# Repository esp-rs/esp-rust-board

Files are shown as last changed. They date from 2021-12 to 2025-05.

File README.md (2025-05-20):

# Rust ESP Board

Welcome to the Rust ESP Development board project. This repository contains everything you will need to build the board yourself.

## Where to buy

* [ESP32-C3-DevKit-RUST-1](https://www.espressif.com/en/products/devkits)
* [AliExpress Espressif Official Store](https://www.aliexpress.com/item/1005004418342288.html)
* [Mouser Electronics](https://www2.mouser.com/ProductDetail/Espressif-Systems/ESP32-C3-DevKit-RUST-1?qs=4ASt3YYao0WvXOj9TGjU2A%3D%3D)
(Note that at least when ordering from the UK and seemingly [EU and Europe](https://www.mouser.co.uk/saleterms/), if you choose to
order through Mouser there is long process instigated by email post-checkout to fill out and then electronically sign or fax export declaration forms
which can add significant delay)

## Ferrous Systems Training

* [Training Book: Explore the power of Rust on the new Espressif board](https://github.com/esp-rs/std-training)
  * [Training Material](https://esp-rs.github.io/std-training/)

## Project Specification

This board is based on the ESP32-C3, and includes sensors, LEDs, buttons, a battery charger, and USB type-C connector.

### SoC Features

* IEEE 802.11 b/g/n-compliant
* Bluetooth 5, Bluetooth mesh
* 32-bit RISC-V single-core processor, up to 160MHz
* 384 KB ROM
* 400 KB SRAM (16 KB for cache)
* 8 KB SRAM in RTC
* 22 × programmable GPIOs
* 3 × SPI
* 2 × UART
* 1 × I2C
* 1 × I2S
* 2 × 54-bit general-purpose timers
* 3 × watchdog timers
* 1 × 52-bit system timer
* Remote Control Peripheral (RMT)
* LED PWM controller (LEDC)
* Full-speed USB Serial/JTAG controller
* General DMA controller (GDMA)
* 1 × TWAI®
* 2 × 12-bit SAR ADCs, up to 6 channels
* 1 × temperature sensor

For the complete description, see the [ESP32-C3 Datasheet](https://www.espressif.com/sites/default/files/documentation/esp32-c3_datasheet_en.pdf).

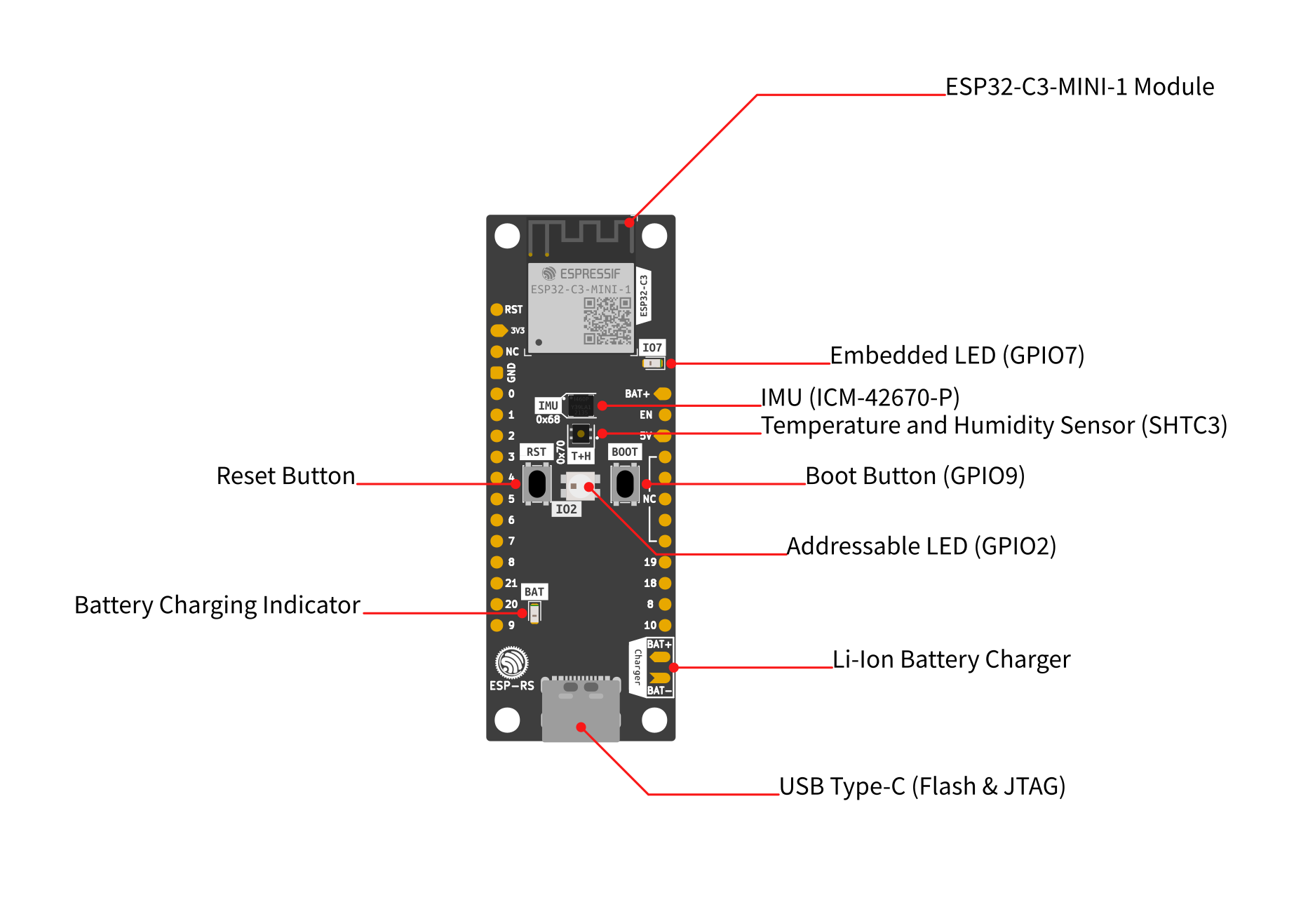
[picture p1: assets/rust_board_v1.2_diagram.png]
Diagram


### I2C Peripherals

This board includes the following peripherals over the I2C bus:

| Peripheral | Part number | Reference | Crate | Address |
| --- | --- | --- | --- | --- |
| IMU | ICM-42670-P | [Datasheet](https://invensense.tdk.com/download-pdf/icm-42670-p-datasheet/) | [Link](https://crates.io/crates/icm42670) | 0x68 |
| Temperature and Humidity | SHTC3 | [Datasheet](https://www.mouser.com/datasheet/2/682/Sensirion_04202018_HT_DS_SHTC3_Preliminiary_D2-1323493.pdf) | [Link](https://crates.io/crates/shtcx) | 0x70 |

#### I2C Bus Connection

| Signal | GPIO |
| --- | --- |
| SDA | GPIO10 |
| SCL | GPIO8  |

### I/Os

The following devices are connected through GPIO:

| I/O Devices | GPIO  |
| --- | ----- |
| WS2812 LED  | GPIO2 |
| LED | GPIO7 |
| Button/Boot | GPIO9 |

### Power

* USB type-C (*no PD compatibility*).
* Li-Ion battery charger - MCP73831T-2ACI/OT, it charges up to 4.2V.
  * Recommendation: MCP73831T-2ACI/OT does not provide battery protection for over-current or over-discharge. For the battery (Li-Ion or Li-Po), it's recommended the ones with embedded protection
  * Limitation: reading the battery voltage is not supported.

### Pin Layout

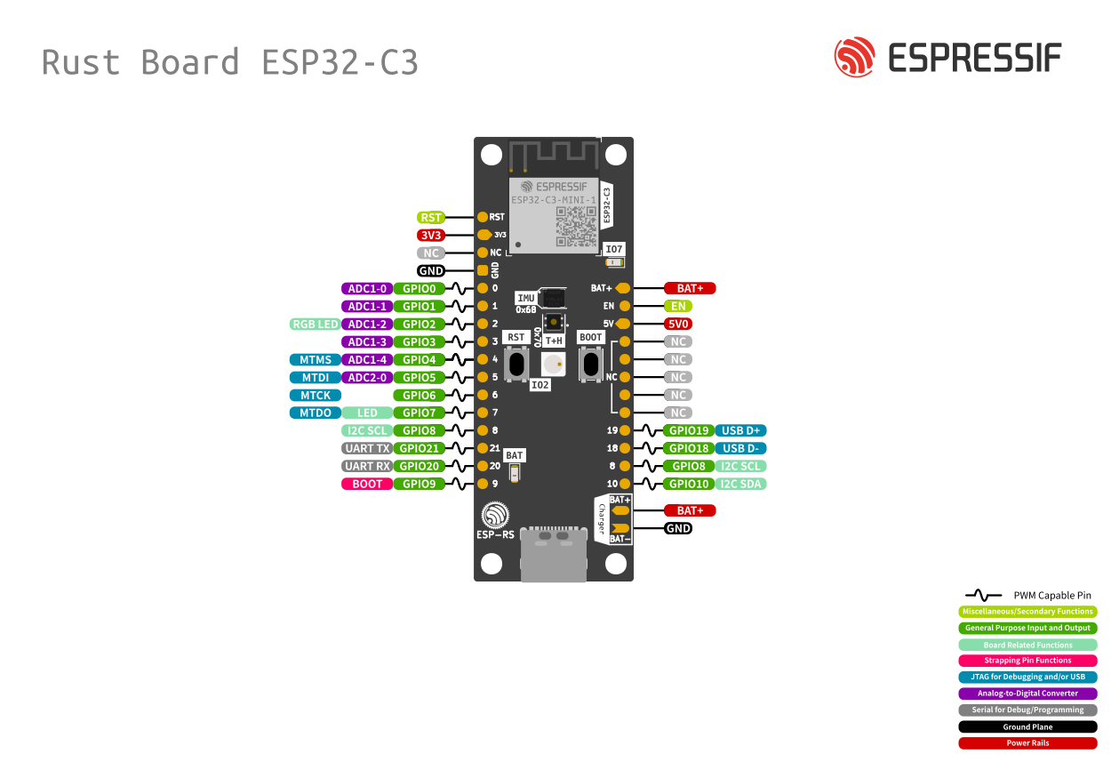
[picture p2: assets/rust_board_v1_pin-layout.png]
Pin Layout


#### Left Side

| Pin Number | Description  | SoC |
| --- | --- | --- |
| 1 | Reset | EN/CHIP_PU |
| 2 | 3V3 | |
| 3 | N/C | |
| 4 | GND | |
| 5 | IO0/ADC1-0 | GPIO0 |
| 6 | IO1/ADC1-1 | GPIO1 |
| 7 | IO2/ADC1-2 | GPIO2 |
| 8 | IO3/ADC1-3 | GPIO3 |
| 9 | IO4/ADC2-0 | GPIO4 |
| 10 | IO5/ADC2-1 | GPIO5 |
| 11 | IO6/MTCK | GPIO6 |
| 12 | IO7/MTDO/LED | GPIO7 |
| 13 | IO9/LOG | GPIO8 |
| 14 | IO21/U0RXD | GPIO21 |
| 15 | IO20/U0TXD | GPIO20 |
| 16 | IO9/BOOT | GPIO9 |

#### Right Side

| Pin Number | Description | SoC |
| --- | --- | --- |
| 1 | VBAT | |
| 2 | EN [1] | |
| 3 | VBUS [2] | |
| 4 | NC | |
| 5 | NC | |
| 6 | NC | |
| 7 | NC | |
| 8 | NC | |
| 9 | IO18/USB_D- | GPIO18 |
| 10 | IO19/USB_D+ | GPIO19 |
| 11 | IO8/SCL | GPIO8  |
| 12 | IO10/SDA | GPIO10 |

  * [1] Connected to LDO enable pin*
  * [2] Connected to USB 5V*

## Project KiCad Libraries

* [ESP32C3](https://github.com/espressif/kicad-libraries)

## Board Design

Top

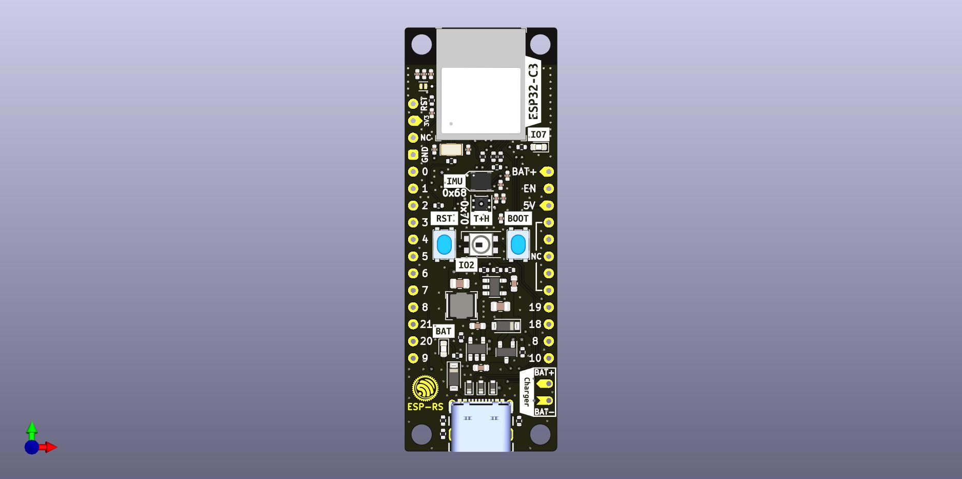
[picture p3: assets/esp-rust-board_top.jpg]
TOP


Bottom

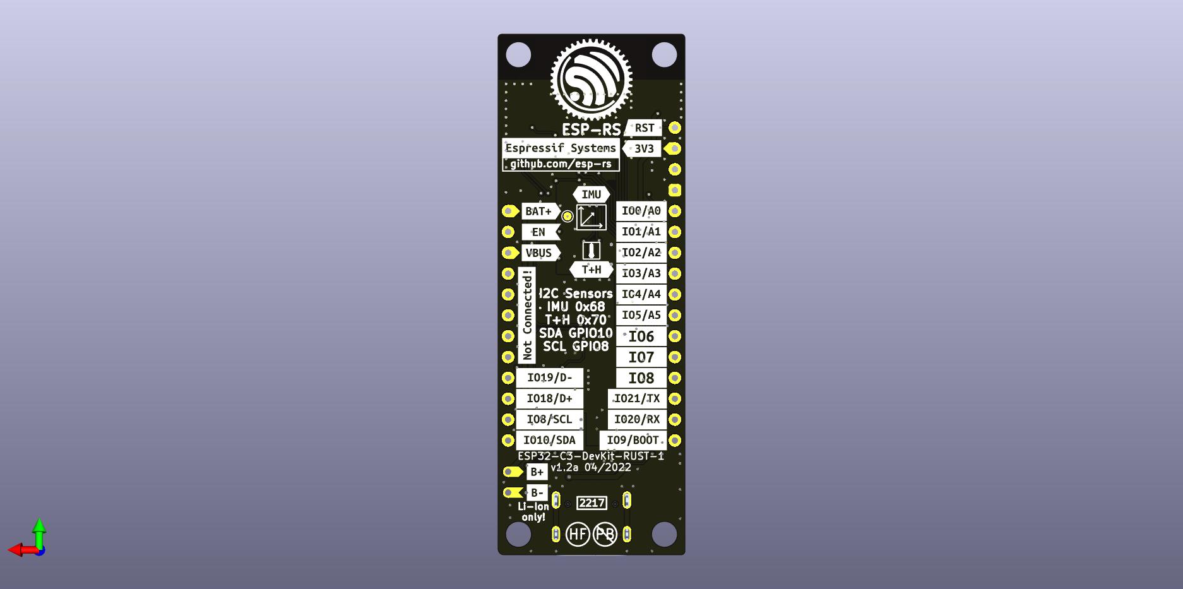
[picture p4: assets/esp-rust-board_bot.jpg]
BOT


## Bill of Material

[Interactive BOM](https://esp-rs.github.io/esp-rust-board/)

## Case

[Case 3D Printing Model](https://www.printables.com/model/288200-minimalistic-case-for-esp32-c3-devkit-rust-1)

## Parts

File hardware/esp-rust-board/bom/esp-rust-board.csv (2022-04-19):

Source: | /home/pedro/Documents/espressif/github/esp-rust-board/hardware/esp-rust-board/esp-rust-board.kicad_sch
Date: | ter 19 abr 2022 15:32:31
Tool: | Eeschema 6.0.1-79c1e3a40b~116~ubuntu21.04.1
Generator: | /usr/share/kicad/plugins/bom_csv_grouped_by_value_with_fp.py
Component Count: | 46
Ref | Qnty | Value | Cmp name | Footprint | Description | Vendor
C1, C2, C11, | 3 | 10nF 10V | C_Small | Capacitor_SMD:C_0402_1005Metric | Unpolarized capacitor, small symbol
C3, C4, C9, | 3 | 100nF 10V | C_Small | Capacitor_SMD:C_0402_1005Metric | Unpolarized capacitor, small symbol
C5, C7, | 2 | 10uF 16V | C_Small | Capacitor_SMD:C_0805_2012Metric | Unpolarized capacitor, small symbol
C6, | 1 | 22pF 50V | C_Small | Capacitor_SMD:C_0603_1608Metric | Unpolarized capacitor, small symbol
C8, C10, | 2 | 1uF 16V | C_Small | Capacitor_SMD:C_0402_1005Metric | Unpolarized capacitor, small symbol
C15, C16, | 2 | 4.7uF 16V | C_Small | Capacitor_SMD:C_0603_1608Metric | Unpolarized capacitor, small symbol
D1, | 1 | LESD8D3.3CAT5G | D_TVS | Rust_Board:SOD-882 | Bidirectional transient-voltage-suppression diode
D2, D3, | 2 | LED | LED | LED_SMD:LED_0603_1608Metric | Light emitting diode
D4, D6, | 2 | B5819W | D_Schottky | Diode_SMD:D_SOD-123 | Schottky diode
D5, D7, D8, | 3 | LESD5D5.0CT1G | D_TVS | Diode_SMD:D_SOD-523 | Bidirectional transient-voltage-suppression diode
J1, | 1 | USB4105-GF-A | USB4105-GF-A | Rust_Board:GCT_USB4105-GF-A
L1, | 1 | SPH4018H2R2MT (2.2uH 2.2A) | L_Small | Inductor_SMD:L_Bourns-SRN4018 | Inductor, small symbol
Q1, | 1 | DMG3415U | DMG2301L | Package_TO_SOT_SMD:SOT-23 | -3A Id, -20V Vds, P-Channel MOSFET, SOT-23
R1, | 1 | 10kR | R_Small_US | Resistor_SMD:R_0402_1005Metric | Resistor, small US symbol
R2, R15, | 2 | 100kR 1% | R_Small_US | Resistor_SMD:R_0402_1005Metric | Resistor, small US symbol
R3, | 1 | 22k1R 1% | R_Small_US | Resistor_SMD:R_0402_1005Metric | Resistor, small US symbol
R4, R6, | 2 | 5k1R 1% | R_Small_US | Resistor_SMD:R_0402_1005Metric | Resistor, small US symbol
R5, R7, | 2 | 0R 1% | R_Small_US | Resistor_SMD:R_0402_1005Metric | Resistor, small US symbol
R8, R9, R17, R18, R19, | 5 | 10kR 1% | R_Small_US | Resistor_SMD:R_0402_1005Metric | Resistor, small US symbol
R10, | 1 | 470R 1% | R_Small_US | Resistor_SMD:R_0402_1005Metric | Resistor, small US symbol
R14, | 1 | 1kR 1% | R_Small_US | Resistor_SMD:R_0402_1005Metric | Resistor, small US symbol
SW1, SW2, | 2 | SW_Push | SW_Push | Button_Switch_SMD:SW_SPST_PTS810 | Push button switch, generic, two pins
U1, | 1 | SHTC3 | SHTC3 | Rust_Board:SON100P200X200X80-5N
U2, | 1 | ICM-42670-P | ICM-42670-P | Rust_Board:IC_ICM-42670-P
U3, | 1 | ESP32-C3-MINI-1 | ESP32-C3-MINI-1 | Espressif:ESP32-C3-MINI-1
U5, | 1 | SY8088 | SY8088 | Package_TO_SOT_SMD:SOT-23-5
U6, | 1 | MCP73831-2-OT | MCP73831-2-OT | Package_TO_SOT_SMD:SOT-23-5 | Single cell, Li-Ion/Li-Po charge management controller, 4.20V, Tri-State Status Output, in SOT23-5 package

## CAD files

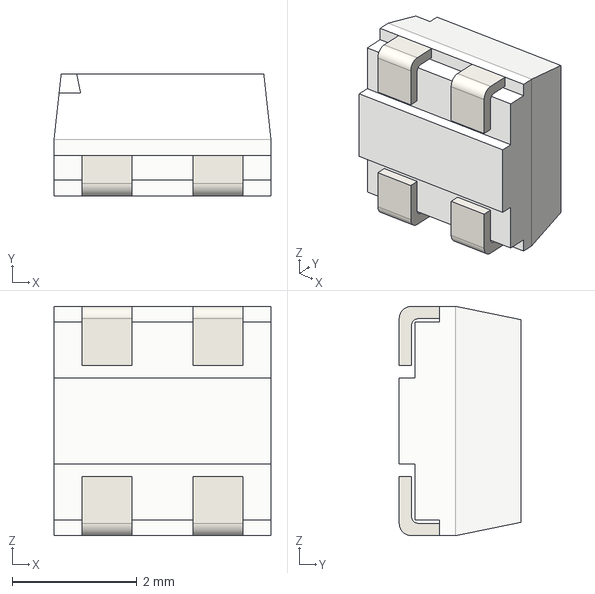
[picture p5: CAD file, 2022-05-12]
kicad_libs/3d/WS2812B-MINI.step
3.48 x 1.95 x 3.68 mm

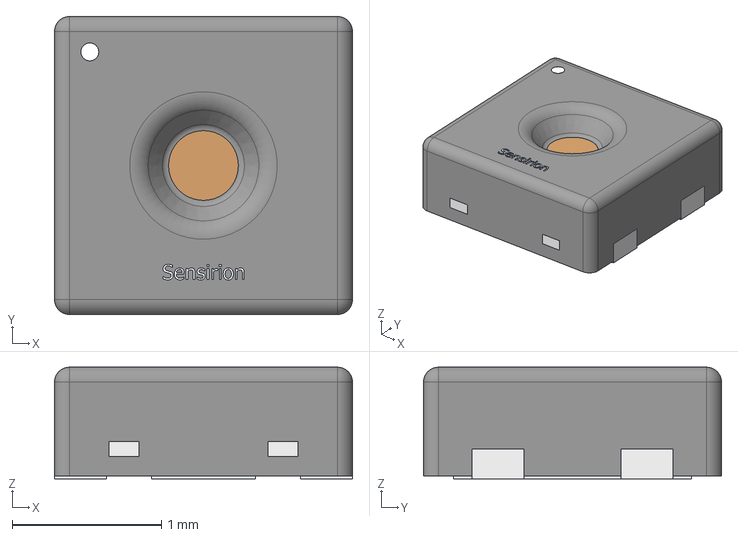
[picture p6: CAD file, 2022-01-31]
kicad_libs/3d/SHTC3.step
2.00 x 2.00 x 0.751 mm

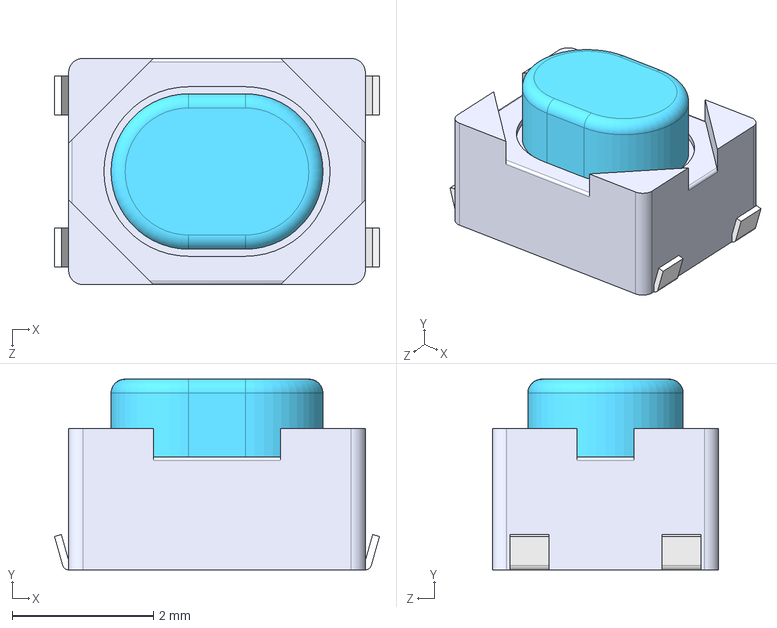
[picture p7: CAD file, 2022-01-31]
kicad_libs/3d/PTS810SJK250SMTRLFS.step
4.60 x 2.70 x 3.20 mm

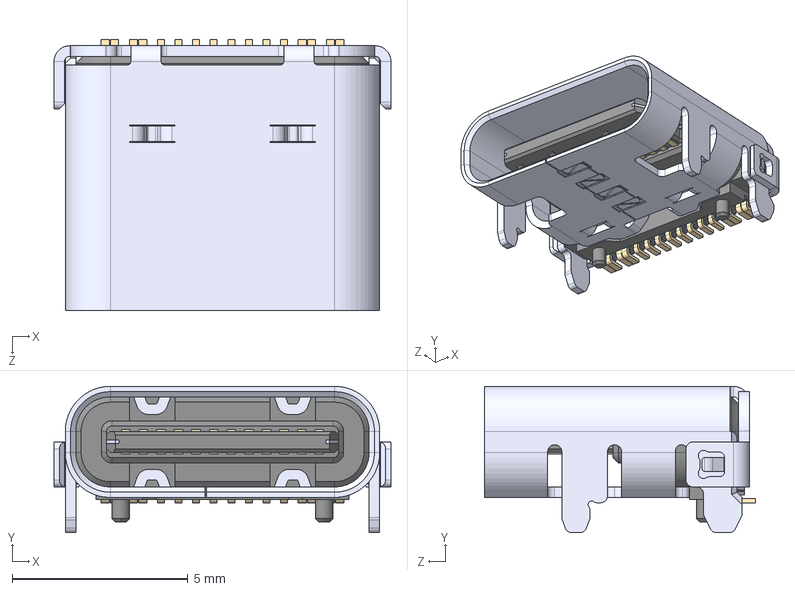
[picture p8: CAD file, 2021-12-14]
kicad_libs/3d/USB4105-GF-A.step
9.58 x 4.16 x 7.71 mm

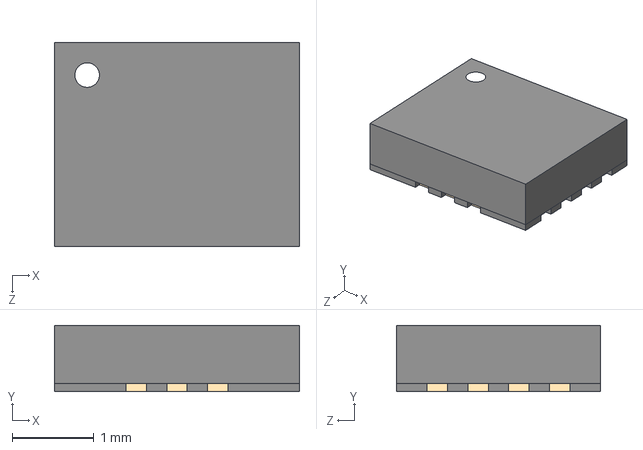
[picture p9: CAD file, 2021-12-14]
kicad_libs/3d/ICM-42670-P.step
3.00 x 0.81 x 2.50 mm

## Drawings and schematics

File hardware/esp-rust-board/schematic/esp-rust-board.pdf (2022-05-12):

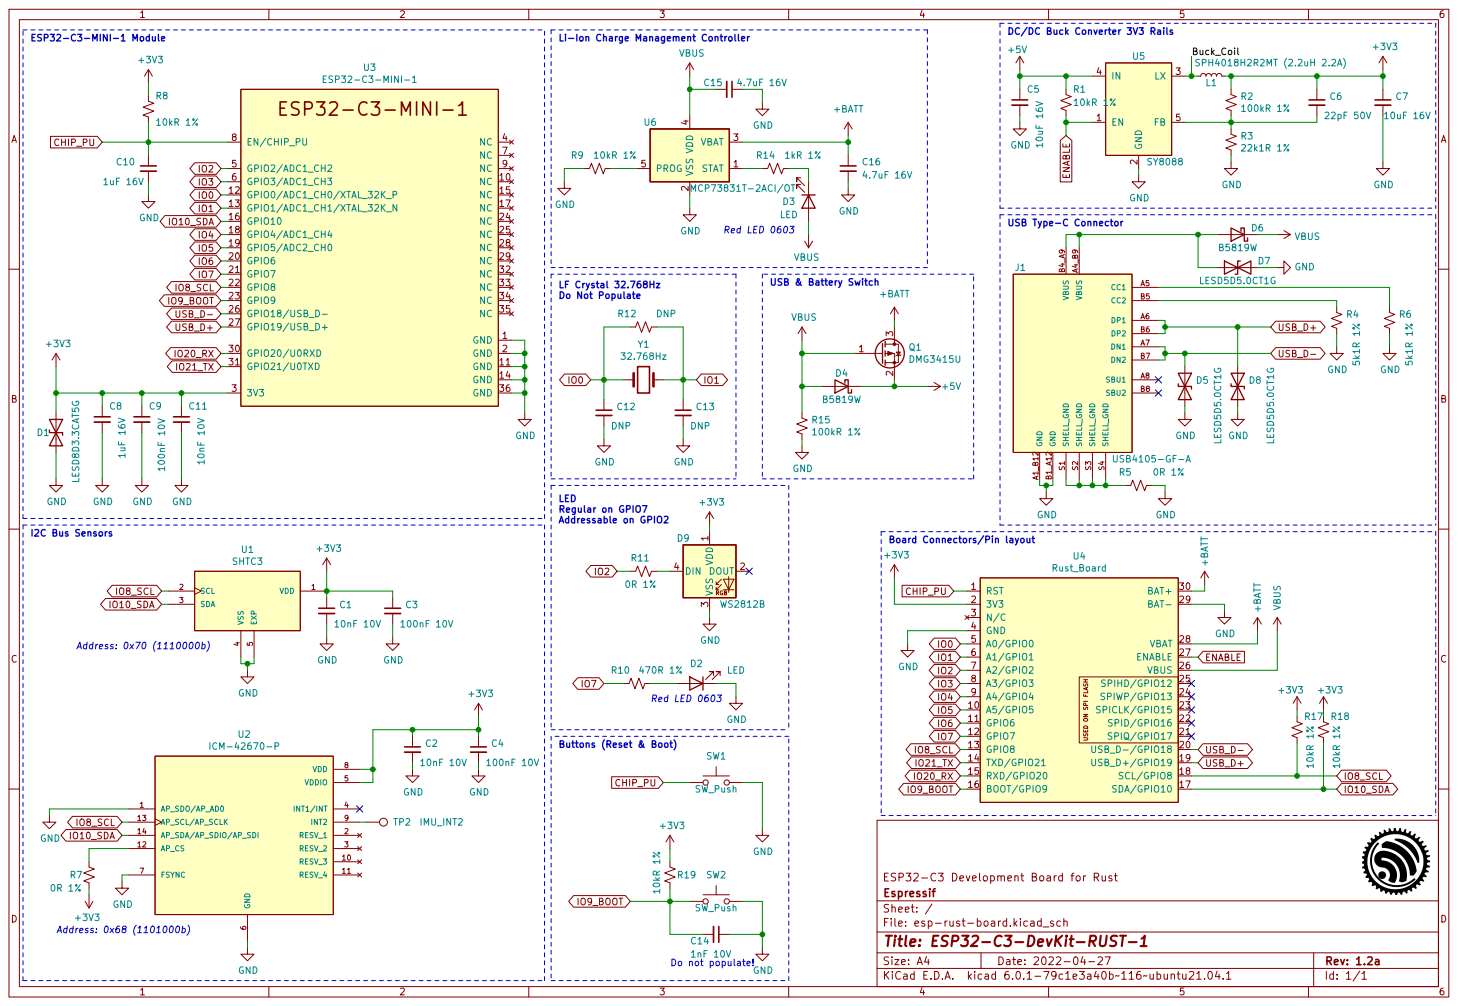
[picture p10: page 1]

Li-Ion Charge Management Controller

ESP32-C3 Development Board for Rust GND

Board Connectors/Pin layout

File: esp-rust-board.kicad_sch Sheet: / Espressif

Id: 1/1 Title: ESP32-C3-DevKit-RUST-1

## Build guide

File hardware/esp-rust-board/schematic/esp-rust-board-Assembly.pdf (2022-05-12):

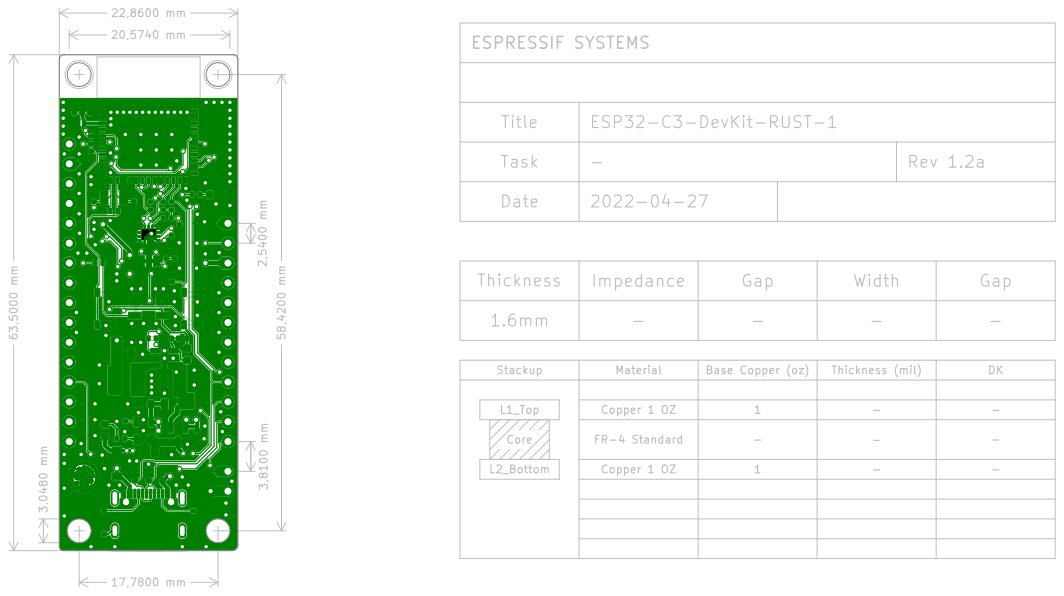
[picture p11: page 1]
D Date: 2022-04-27 KiCad E.D.A. kicad 6.0.1-79c1e3a40b~116~ubuntu21.04.1 Size: A4; Rev: 1.2a; - Stackup; Thickness (mil) L1_Top 1.6mm; Width; - Gap Date Thickness; Rev 1.2a ESPRESSIF SYSTEMS; Core; Gap; L2_Bottom; 1 Title; REF**; PCB-EDGE

ESP32-C3-DevKit-RUST-1 Task

2022-04-27
- Copper 1 OZ | | | DK

- Copper 1 OZ Material Impedance

- Base Copper (oz)

1 | - FR-4 Standard

Espressif Systems
Sheet: Assembly
File: esp-rust-board.kicad_pcb
Id: 1/1 Title: ESP32-C3-DevKit-RUST-1

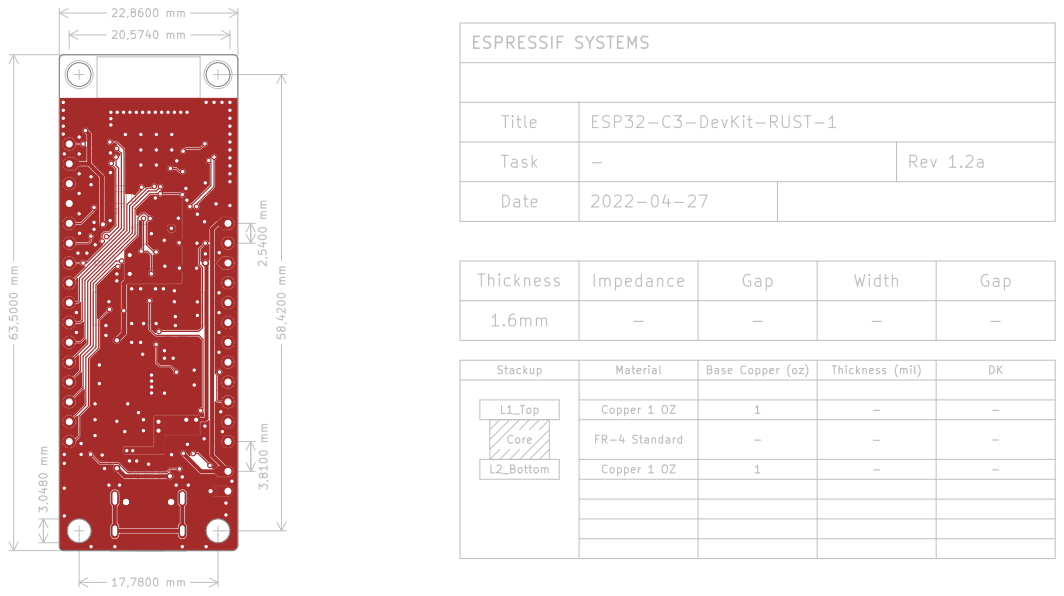
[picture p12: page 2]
D Date: 2022-04-27 KiCad E.D.A. kicad 6.0.1-79c1e3a40b~116~ubuntu21.04.1 Size: A4; Rev: 1.2a; - Stackup; Thickness (mil) L1_Top 1.6mm; Width; - Gap Date Thickness; Rev 1.2a ESPRESSIF SYSTEMS; Core; Gap; L2_Bottom; 1 Title; REF**; PCB-EDGE

ESP32-C3-DevKit-RUST-1 Task

- Copper 1 OZ Material Impedance

- Copper 1 OZ | | | DK

- Base Copper (oz)

1 | - FR-4 Standard

Espressif Systems
Sheet: Assembly
File: esp-rust-board.kicad_pcb
Id: 1/1 Title: ESP32-C3-DevKit-RUST-1

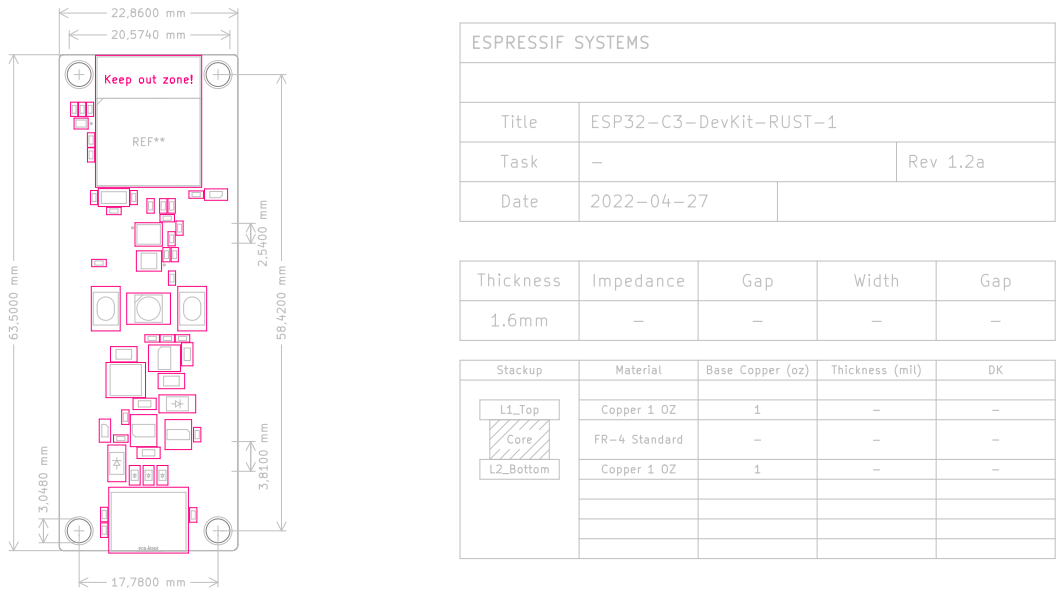
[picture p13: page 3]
D Date: 2022-04-27 KiCad E.D.A. kicad 6.0.1-79c1e3a40b~116~ubuntu21.04.1 Size: A4; Rev: 1.2a; - Stackup; Thickness (mil) L1_Top 1.6mm; Width; - Gap Date Thickness; Rev 1.2a ESPRESSIF SYSTEMS; Core; Gap; L2_Bottom; 1 Title; REF**

PCB-EDGE Keep out zone!

ESP32-C3-DevKit-RUST-1 Task

- Copper 1 OZ Material Impedance

- Copper 1 OZ | | | DK

- Base Copper (oz)

1 | - FR-4 Standard

Espressif Systems
Sheet: Assembly
File: esp-rust-board.kicad_pcb
Id: 1/1 Title: ESP32-C3-DevKit-RUST-1

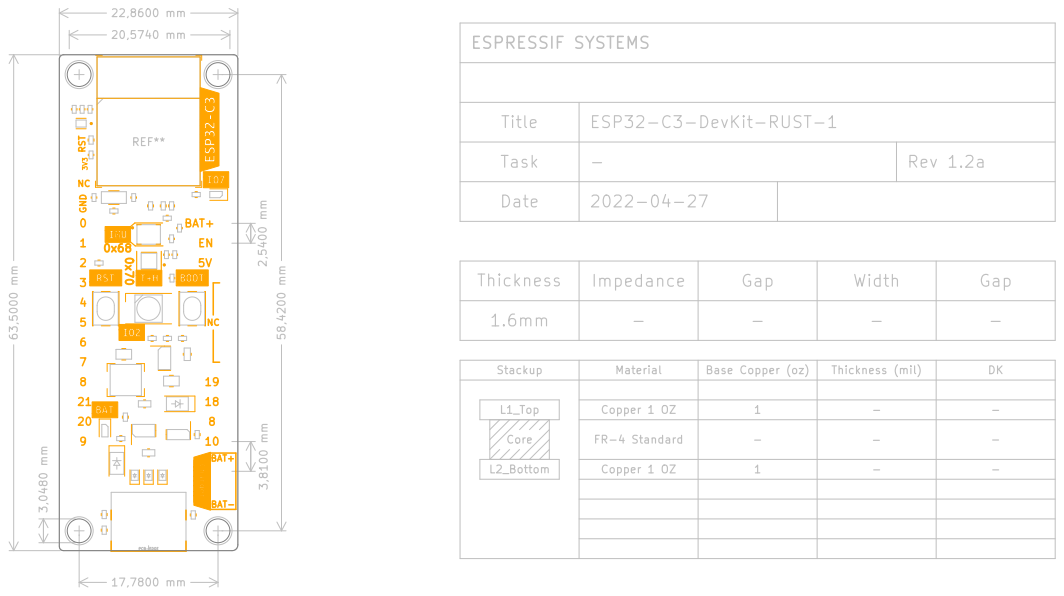
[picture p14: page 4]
D Date: 2022-04-27 KiCad E.D.A. kicad 6.0.1-79c1e3a40b~116~ubuntu21.04.1 Size: A4; Rev: 1.2a; - Stackup; Thickness (mil) L1_Top 1.6mm; Width; - Gap Date Thickness; Rev 1.2a ESPRESSIF SYSTEMS; Core; Gap; L2_Bottom; 1 Title; REF**; PCB-EDGE; BAT+ ³V³; 20GND; 0RST 9; BAT+ 1; 2 BAT- 10

ESP32-C3-DevKit-RUST-1 Task

- Copper 1 OZ Material Impedance

- Copper 1 OZ | | | DK

- Base Copper (oz)

1 | - FR-4 Standard

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

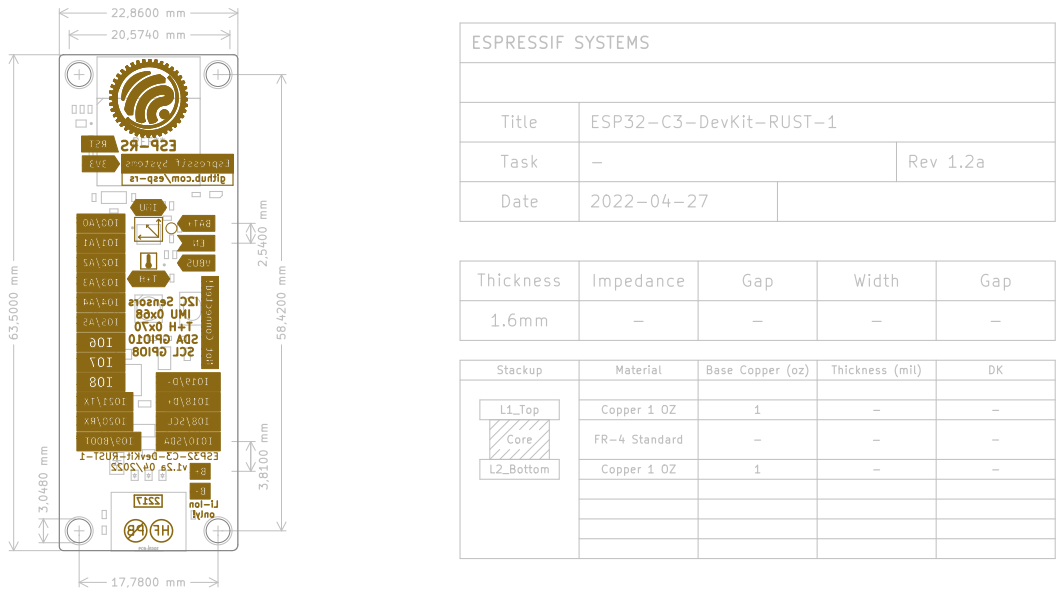
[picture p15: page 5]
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

ESP32-C3-DevKit-RUST-1 Task

- Copper 1 OZ Material Impedance

- Copper 1 OZ | | | DK

- Base Copper (oz)

1 | - FR-4 Standard

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

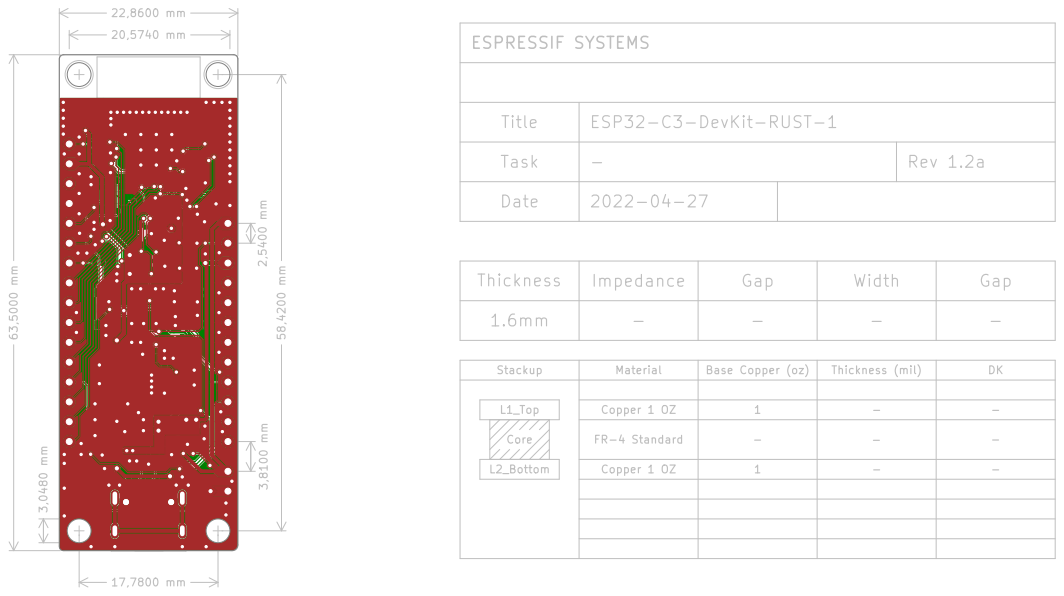
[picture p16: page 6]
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

ESP32-C3-DevKit-RUST-1 Task

2022-04-27
- Copper 1 OZ | | | DK

- Copper 1 OZ Material Impedance

- Base Copper (oz)

1 | - FR-4 Standard

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

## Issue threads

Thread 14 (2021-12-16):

Check Feather Wings compatability with the current pin layout

pedrominatel, 2021-12-16:
Check Feather Wings compatability with the current pin layout

pedrominatel, 2021-12-16:
Adafruit FeatherWing OLED - 128x64 OLED Add-on For Feather

https://www.adafruit.com/product/4650

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

I2C are ok.
Check: A, B and C pins.

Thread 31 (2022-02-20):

Relicense under a permissive, non-viral license

TheButlah, 2022-02-20:
CERN-OHL-S v2 is a copyleft, non-permissive license, much in the same way that GPLv3 is. For the same motivations on why the rest of the rust ecosystem is licensed under Apache 2.0/MIT, would it be possible to re-license under a new license that is permissive and not reciprocal/viral?

I don't know much about hardware licenses, but according to #8  it seems that the particular variant of the CERN license was chosen somewhat arbitrarily. Unlike the S variant, the P variant (CERN-OHL-P v2) is permissive, which means the following (IANAL):

* Unlike S variant, modified source does not need to be licensed under the same license.
* All the license notices still need to be provided (including the notice printed on the PCB that it is a CERN-OHL-P v2 license), but unlike S variant, notices that are no longer relevant due to modification and subsequent re-license can be omitted.
* Unlike the S variant, distributing source along with the full product is merely optional.

Switching to the P variant (CERN-OHL-P v2) would address the concerns I have and bring the license more in line with the approach that licenses like the MIT license and Apache 2.0 license take.

TheButlah, 2022-02-20:
Citations:
* [P variant user guide](https://ohwr.org/project/cernohl/wikis/uploads/8a6b5d01f71c207c49493e4d114d61e6/cern_ohl_p_v2_howto.pdf) [
* [S variant user guide](https://ohwr.org/project/cernohl/wikis/uploads/cf37727497ca2b5295a7ab83a40fcf5a/cern_ohl_s_v2_user_guide.pdf)
* https://ohwr.org/project/cernohl/wikis/Documents/CERN-OHL-version-2

TheButlah, 2022-02-20:
To clarify: the current license requires source to be provided (things can not be closed source), and it requires derivative works to use the same license (license is viral).

These are properties of licenses the rust ecosystem generally desires to avoid

georgik, 2022-02-22:
Channing license to more permissive makes sense. The board is for community and businesses, it does not make sense to force any restrictions on it.

Closed 2022-02-28.

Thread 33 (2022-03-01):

SHELL_GND should be floating

TheButlah, 2022-03-01:
Disclaimer: I have almost no electronics experience. Please verify my advice with someone with actual electrical engineering experience.

I believe the `SHELL_GND` pins on the USB-C connector should not be grounded, but rather should be floating. This is to prevent ESD and EMI (I think)

Citation:
https://forum.sparkfun.com/viewtopic.php?p=102538&sid=b578afcca223f70d7e8433f18a3f1d76#p102538

julian19072001, 2022-03-01:
Not exactly what I ment. You should connect it to ground through a 1 mega ohm resistor. And not disconnect it. This is both to prevent it acting as an antenna and a esd safety thing.

TheButlah, 2022-03-14:
More conflicting advice:
https://forum.allaboutcircuits.com/threads/usb-device-cable-shield-connection-grounding-it-or-not.58811/

pedrominatel, 2022-03-14:
Hi @TheButlah,

Thanks for your contribution! We just received the first testing batch and maybe more changes will be done for the second/final version.

Usually, Espressif development board connects the USB shield to GND directly. For development boards this is ok and in most cases, EMI is not relevant.
We did connect the shield to GND but this does not mean that every project should be like.

Anyway, we can add a 0R resistor to the design and the user can evaluate if it's necessary to add a capacitor or resistor ;)

TheButlah, 2022-03-14:
Sounds good! In my design I opted for a ~100K resistor, but yeah I think this is not necessary at all

Closed 2022-04-12.

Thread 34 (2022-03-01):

Update missing 3d models to use ${KICAD6_3DMODEL_DIR} where possible

TheButlah, 2022-03-01:
Most of the 3d models use the old ${KISYS3DMOD} environment variable, causing all the 3d models for the basic components to be missing. KICAD 6 introduces ${KICAD6_3DMODEL_DIR} to point to the new v6 models.

Not all the models from v5 exist in v6 - notably, I'm seeing that `SW1`, `SW2`, `Y1`, `L1` are broken - not sure if they exist in v6 or not, but at least some of them don't.

I'll submit a PR to upgrade the models to the v6 variable where I can, and leave the old variable for the missing ones. I think this will be a manual process unfortunately, but if anyone knows an automated way to do this, lmk

Relevant: https://forum.kicad.info/t/3d-models-are-missing-in-3d-viewer-after-updating-to-v6/33956

TheButlah, 2022-03-01:
According to [this](https://gitlab.com/kicad/code/kicad/-/issues/10459), it looks like what the Kicad maintainers have intentionally chosen is to bring over the footprints even if the 3d models are missing, and encode the footprints as having the new environment variable instead of the old one. When the main kicad 3d library eventually adds the models back in, the footprints will naturally use the new updated models.

So I guess the migration path for now is either to accept that some of the models don't exist in v6 and wait for them to be added/open an issue in kicad. I guess the alternative would be to keep the old environment variable in for the missing ones?

I think for now since I'm not sure what y'all want, I will stick with my original plan and migrate only the footprints that have v6 models.

TheButlah, 2022-03-01:
After accidentally erasing all of the alternative 3d models y'all so carefully put in there when I nuked the project with "tools -> update footprints from library -> update/reset 3d models", I realized that the "missing" v5 parts had already been imported into the 3d models library in this repo, and set as alternate models.

I went back and manually added back in these alternate models, along with the rotation/scaling edits that were there originally. I then went ahead and switched the path variable to the new `${KICAD6_3DMODEL_DIR}` instead of the old one, as that way when those symbols eventually do get added to upstream kicad, they will supersede the local versions.

pedrominatel, 2022-03-14:
Thanks again for your contribution!

Right now I'm doing the electrical tests on the first batch and soon I'll take care of all changes, including yours.

Closed 2022-04-07.

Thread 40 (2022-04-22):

The question about MCP73831-2-OT

YuaXan, 2022-04-22:
Hello, @pedrominatel.
The BOM sheet has a charge management controllers name's MCP73831-2-OT, but I review an MCP73831/2 datasheet and found many models.
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

I don't know if I should choose what model.

please provide a model name, thanks.

pedrominatel, 2022-04-22:
Hi, the one used on our first batch was the **MCP73831T-2ACI/OT**, but I've also tested with the MCP73831T-2DCI/OT.

I'll update the BOM to include the full MPN **MCP73831T-2ACI/OT** as the default.

Thanks!

YuaXan, 2022-04-22:
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

I used  **MCP73831T-2ATI/OT** happened interruption of the **STAT** port with **VBAT** port.
And  **VBAT** port connects with MOSFET's drain.
When 5V connects to the broad that **VBAT** appears waveforms affect MOSFET's drain which is the cause of 3.3V precarious.
I am not sure the 3.3v precarious what the cause used  **MCP73831T-2ATI/OT**, and I will try to use **MCP73831T-2ACI/OT**  to test.

pedrominatel, 2022-04-22:
Can you share more details about your test and the results?

YuaXan, 2022-04-22:
> Can you share more details about your test and the results?

of course.
I flash reprogramming from [ESP32-C3 AT Release v2.3.0.0](https://docs.espressif.com/projects/esp-at/en/release-v2.3.0.0_esp32c3/).
When I used **MCP73831T-2ATI/OT**, Windows and Linux can't Identify the device cause of 5v to 3.3v precarious, because I try only using 3.3v and TTL to Test which is normal, but only using a USB power supply.
And then I found the same frequency of the **STAT** port as the **VBAT** port in the oscillograph, so I think **MCP73831T-2ATI/OT** is Incompatible with the broad.
Waiting A few days later for **MCP73831T-2ACI/OT** to come, I'll tell you about the new test results.

YuaXan, 2022-04-22:
> Can you share more details about your test and the results?
I dismantle the **MCP73831T-2ATI/OT** and jump wire.
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

pedrominatel, 2022-04-22:
Here are some measurements for both MCP options.
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

pedrominatel, 2022-05-02:
Any news about your issue @YuaXan?

YuaXan, 2022-05-02:
> Any news about your issue @YuaXan?
MCP73831T-2ATI/OT
![e00d10e262c3dc2d195f6eda9391dea](https://user-images.githubusercontent.com/28106851/166223406-f7fab568-2a68-4720-90fc-98d
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
6f0bb7b33.png)

pedrominatel, 2022-11-07:
Hi, any updates about this issue?

Can we close this issue?

pedrominatel, 2022-11-21:
I'm closing this issue due to inactivity.

Closed 2022-11-21.

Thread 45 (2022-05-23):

QR code link to the training

jonathanpallant, 2022-05-23:
Do you think you'd have space on the board for a QR code which links to the training material and/or other docs for the board?

jonathanpallant, 2022-05-23:
Controversial thought perhaps, but seeing as the module on the top-side already has the Espressif logo on it, you could shrink the Espressif logo on the bottom-side to make room for a QR code.

pedrominatel, 2022-05-25:
Hi @jonathanpallant!

Thanks for your suggestion!

I've some consideration regarding this:

- Boards are in production, we can't change anything now
- The silkscreen quality is not the best for small QR codes (considering the space we have)
- As an alternative, we can reduce the logo as you suggested and add a short link, not QR (similar to the GH link)
- QR as footprint with ENIG finishing
- Create a custom cardboard box with the links, QR code, logo, etc.

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

jonathanpallant, 2022-05-26:
Putting the QR code or some other link on the box would be great. How were you planning on shipping/distributing the esp-rust boards?

pedrominatel, 2022-05-27:
The same way Espressif does for any dev board. via distributors and directly for bulk.

jonathanpallant, 2022-05-27:
Ah, I meant in an ESD bag or in a box like the ESP8684-DevKitM-1 pictured above?

pedrominatel, 2022-05-31:
Sorry for the delay! I will depend. Both ways are possible.

Closed 2023-02-23.

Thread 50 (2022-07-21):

Change the size of the hole for the pin headers (feather footprint)

pedrominatel, 2022-07-21:

mygnu, 2022-08-27:
👍🏾

besselfunct, 2022-08-29:
Can confirm that square profile header pins do not fit on my board. I was able to find some circular ones which worked though.

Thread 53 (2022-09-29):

board dimensions

kauly, 2022-09-29:
I can't find the board dimensions anywhere, can you guys provide them?

pedrominatel, 2022-11-07:
Hi,

PTAL here

https://github.com/esp-rs/esp-rust-board/blob/78a57479f640caded03caf177b8a1120efa5c862/hardware/esp-rust-board/schematic/esp-rust-board-Assembly.pdf

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

kauly, 2022-11-07:
thank you sir

Closed 2022-11-07.

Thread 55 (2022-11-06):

Should  GPIO2 have a pull-up?

TheButlah, 2022-11-06:
In the reference manual for the ESP32-C3, the strapping pins are as follows:
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

It looks like GPIO2 should be pulled up, but this board appears to not do so. Is this intentional?

pedrominatel, 2022-11-07:
Hi @TheButlah

Considering this is a development board, the GPIO8 is in high impedance and the user should care about it. In a product, the recommendation is to pull-up or pull-down (depending on the pin function) any pin that is in input enabled state and high impedance during the boot.

In this particular case, it's ok not having the pull-up.

pedrominatel, 2022-11-07:
Hi,

This project was based on the [ESP32-C3-DevKitM](https://dl.espressif.com/dl/schematics/SCH_ESP32-C3-DEVKITM-1_V1_20200915A.pdf).

The GPIO2 is floating on the DevKitM and on the Rust Board is connected to the RGB LED.

Are you facing some unexpected behavior when using the GPIO2 pulled down during the boot?

TheButlah, 2022-11-07:
I have [my](https://github.com/TheButlah/slimevr_pcb/tree/main/hardware/ferrous_slime) own PCB that I used the rust board as a reference for. I'm having USB problems (present in my v0.3.0 but not v0.1.0 strangely, and yet no modifications to the USB part of the circuit were made), and I thought that maybe the GPIO2 was the cause.

Hence the question - I see in section 6 of the esp32-c3-mini reference that they connect GPIO2 to a pull-up, so I thought that maybe my v0.1.0 and the rust board both got lucky, but my v0.3.0 was unlucky.

Is it true that a floating pin is fine?

pedrominatel, 2022-11-07:
Please take a look at page 21 in the datasheet.

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

Depending on the state of the GPIOs, you can face an issue during the boot process.

Can you confirm the initial state of the following GPIOs?

- GPIO9
- GPIO8
- GPIO3
- GPIO2

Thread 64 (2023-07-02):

SHTC3 Sensor Placement

urish, 2023-07-02:
I've been running the awesome Rust Board for several hours, and as expected, the ESP32-C3 module gets a bit warm. Unfortunately, this affects the SHTC3 sensor readings in a significant way (I measured more than 5 °C error, which also greatly affects the relative-humidity reading, as it's temperature-compensated).

I suggest moving the SHTC3 as far as possible from the ESP32-C3 module, to mitigate this issue. I don't have any thermal imaging hardware here, but it seems like the bottom of the board, next to the USB-C connector, is more or less at the ambient temperature, so it might be a better place for the SHTC3 in future revisions of the board.

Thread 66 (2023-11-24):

Suggestion: Header pins types and battery and connector JST PH-2

elpiel, 2023-11-24:
I would like to suggest to:
-  switch the circular header pins that are currently on the board PCB
  They are easy to break if you're doing a project on a breadboard
- Adjust the PCB to support a JST PH-2 connector for the battery

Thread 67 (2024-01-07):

Adding 32kHz crystal?

morrowa, 2024-01-07:
I'm interested in using a 32768Hz external crystal to enable [modem sleep during light sleep.](https://github.com/espressif/esp-idf/issues/947#issuecomment-1484382679)

I see in the schematic and PCB layout that there are unpopulated pads for a 32768Hz crystal along with supporting passives. However, I could not find any information on the part values.

What are the required values/tolerances for R12, C12, C13, and Y1?

Thank you!

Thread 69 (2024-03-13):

Can't read I2C addresses 0x70 and 0x68

houssemFat, 2024-03-13:
Hello and thank you for the great work.

I recently purchased the esp rust board.  As it is based on esp32 C3, i tried with some arduino sketches using arduino IDE and arduino-esp standard library. Codes are ok with RGB (WS2812), serial output and build in led (GPIO7) (using the `LOLIN C3 mini` as the board for arduino ide) .

I'm assuming that the board is arduino compatible (please correct me if i'm wrong).

Now, i'm trying to read values from the onboard sensors   (SHTC3 and ICM-42670-P) using the given i2c addresses  (0x68 & 0x70). I'm using a dummy I2C scanner, but it keeps getting error code 2.

I tried the many arduino library for  SHTC3 (eg: [Adafruit_SHTC3](https://github.com/adafruit/Adafruit_SHTC3) with no luck.

### Scanner code

```

/*********
  Rui Santos
  Complete project details at https://randomnerdtutorials.com
*********/

#include <Wire.h>
void setup() {
  Wire.begin();
  Serial.begin(115200);
  Serial.println("\nI2C Scanner");
}

void loop() {
  byte error;
  delay(2000);
  // replace with 0x70 for SHTC3
  // ICM-42670-P
  Wire.beginTransmission(0x68);
  error = Wire.endTransmission();
  if (error == 0) {
    Serial.println("OK, Found");
  }else {
    Serial.println("NOT OK ");
     Serial.println(error);
  }
  delay(2000);  
}
```
### Output
```
23:37:27.896 -> NOT OK
23:37:27.896 ->
```

Am I missing something ? Maybe using a wrong board definition ?
I appreciate any help !

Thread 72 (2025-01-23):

c6 plans?

jamessizeland, 2025-01-23:
Are there any plans for a respin of this board with a c6 chip in future?

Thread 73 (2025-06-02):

Kicad symbol inconsistency

MochiButter, 2025-06-02:
The names used for the pins [10](https://github.com/esp-rs/esp-rust-board/blob/efe1e8ad5c6dbc23b4365fef35af27545bc1381d/kicad_libs/Rust_Board.kicad_sym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) and [9](https://github.com/esp-rs/esp-rust-board/blob/efe1e8ad5c6dbc23b4365fef35af27545bc1381d/kicad_libs/Rust_Board.kicad_sym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) in the rust board symbol are inconsistent with other sources.
The pin layout diagram, as well as the printing on the bottom of the board has GPIO4 on the same pin as ADC4, and GPIO5 with ADC5.
The ADC numbers in the symbol file should be swapped from 4 to 5, respectively.

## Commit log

2021-11-19 Added gitignore file for KiCad projects
2021-11-19 Added KiCad project template
    [esp-rs_craboard.kicad_pcb, esp-rs_craboard.sch]
2021-12-06 Readme updated and board outline image created
2021-12-09 Added kicad board library Added kicad board symbol [Docs] Changes on outline footprint [Fix] Worng GPIO for D- fixed
2021-12-09 [Fix] Fix issues on the pin layout description and typos.
2021-12-10 [Feature] Added new symbols, footprints and 3d models
    [ICM-42670-P.step, SHTC3.step, USB4105-GF-A.step]
2022-01-31 Rust Board project port to KiCad v6 Schematic created based on ESP32-C3 PCB design Fabrication files added
    [PTS810SJK250SMTRLFS.step, SHTC3.step, esp-rs_craboard.kicad_pcb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]
2022-03-01 Fixed broken footprint assignment on U4 Migrated old .lib symbol library to .kicad_sym Migrated missing v5 3d models to v6 3d models where possible Updated PCB from schematic changes
    [esp-rust-board.kicad_pcb, esp-rust-board.kicad_sch]
2022-03-01 Added project-local footprint and symbol libs
2022-04-07 [PCB] Fixed the IO4 and IO5 front silk-screen
    [esp-rust-board.kicad_pcb]
2022-04-07 [PCB] ESP32-C3 footprint updated to latest
    [esp-rust-board.kicad_pcb]
2022-04-07 [PCB] Added the 0R resistor to USB shield and GND
    [esp-rust-board.kicad_pcb, esp-rust-board.kicad_sch]
2022-04-07 Revision v1.1 - Changes on the labels, fixes, small logo and other minor fixes
    [esp-rust-board-B_Cu.gbr, esp-rust-board-B_Mask.gbr, esp-rust-board-B_Paste.gbr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]
2022-04-07 Manufactoring files updated
    [esp-rust-board-B_Cu.gbr, esp-rust-board-B_Mask.gbr, esp-rust-board-B_Paste.gbr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]
2022-04-07 Rebase and sync from master
    [esp-rust-board-B_Cu.gbr, esp-rust-board-B_Mask.gbr, esp-rust-board-B_Paste.gbr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]
2022-04-07 Rebase and sync from master board
    [esp-rust-board.kicad_pcb]
2022-04-19 Added POS and BOM files. Gitignore file updated
    [esp-rust-board.csv, esp-rust-board.kicad_sch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]
2022-04-27 Mention board availability
    Just add a quick note to let the community know that manufactured boards will be available soon
2022-04-27 Added the WS2812 LED for the next prototype production
    [esp-rust-board-B_Cu.gbr, esp-rust-board-B_Mask.gbr, esp-rust-board-B_Paste.gbr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]
2022-05-02 Version 1.2 review 0 - Added addressable LED
    [WS2812B-MINI.step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]
2022-05-02 Added 3d board image preview
2022-05-02 Added BOM and PnP files. README and .gitignore files updated
    [esp-rust-board.csv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]
2023-01-23 Update README.md (#56)
    We can now remove the sentence "Manufactured boards will be available soon, at which point a purchase link will replace this text."
2023-02-24 feat: ✨ Update training links (#59)
2023-02-24 Add link to 3d printed case (#60)
2023-03-13 Fix broken links (#62)
    * feat: ✨ Update training links
    * fix: 🐛 Fix broken links
2023-06-01 feat: ✨ Update STD trainings links (#63)
2024-02-20 doc: add information about IC charger
